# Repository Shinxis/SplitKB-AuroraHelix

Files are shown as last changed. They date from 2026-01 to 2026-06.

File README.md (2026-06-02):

# SplitKB Aurora Helix
An ergonomic split keyboard with ortholinear grid layout, using Aurora Helix from [splitkb.com](https://splitkb.com)

Here are the 3D design files for the keyboard case, including the:
- top plates,
- controller covers,
- bottom plates,
- bottom plate molds for casting them from epoxy.

The files types are:
- The complete 3D model in a FreeCAD file
- The exported parts in STL files
- Bambu Studio project files ready to print on a bambu printer.

<br>

# Build log
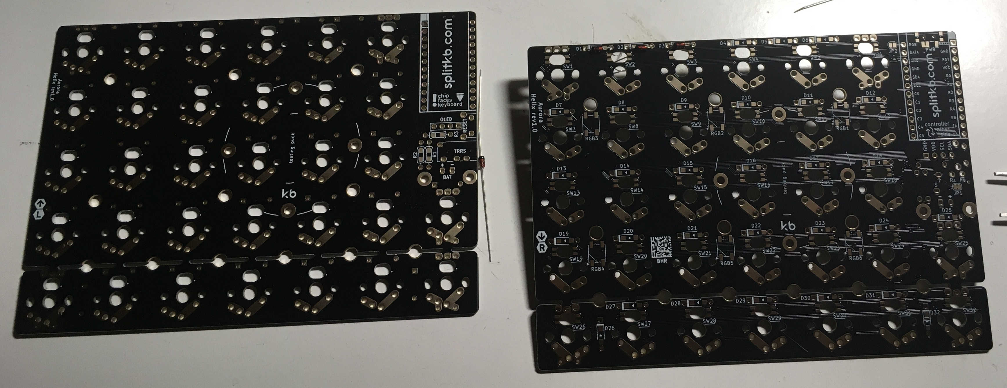
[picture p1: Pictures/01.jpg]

Arrived.

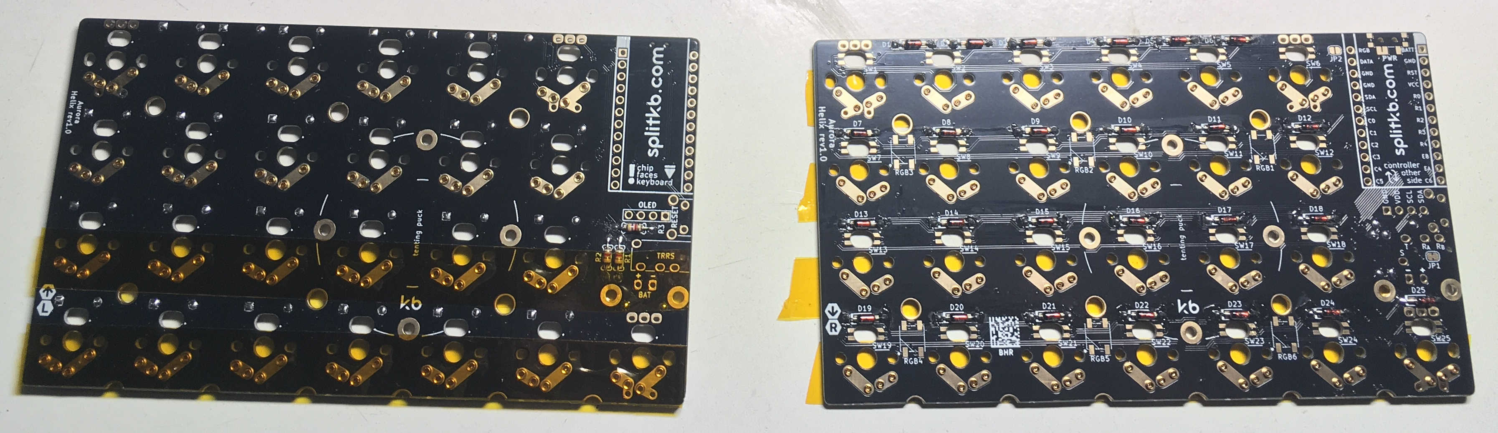
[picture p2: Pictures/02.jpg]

Low row cut off. Using Kapton tape to hold the MillMax sockets and components in place.

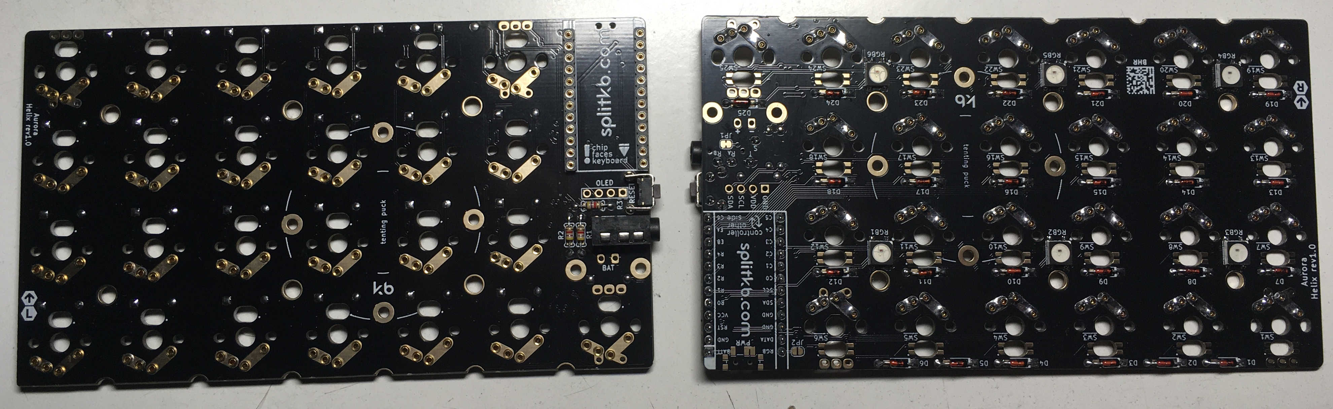
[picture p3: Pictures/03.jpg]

Soldered.

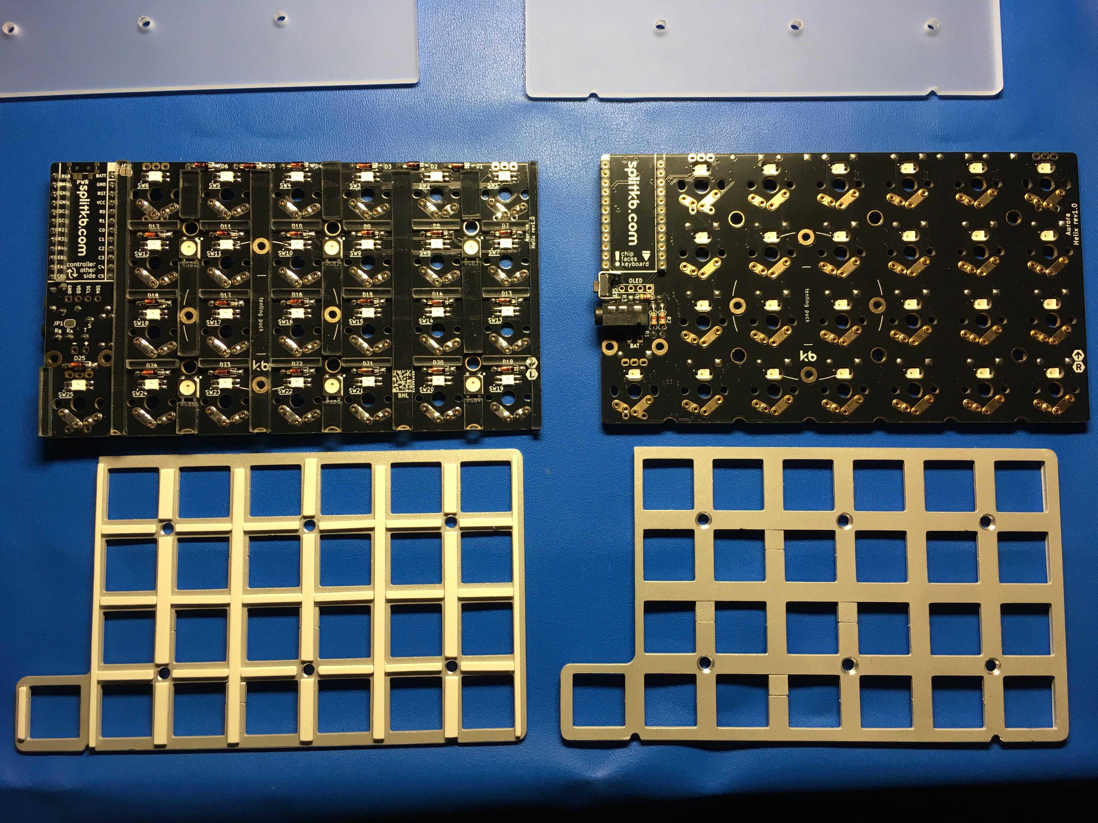
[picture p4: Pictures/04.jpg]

Adding spacers between the plates in order to make a tight stack. Later discarded in order to cut off some height and to use a 3D printed case.

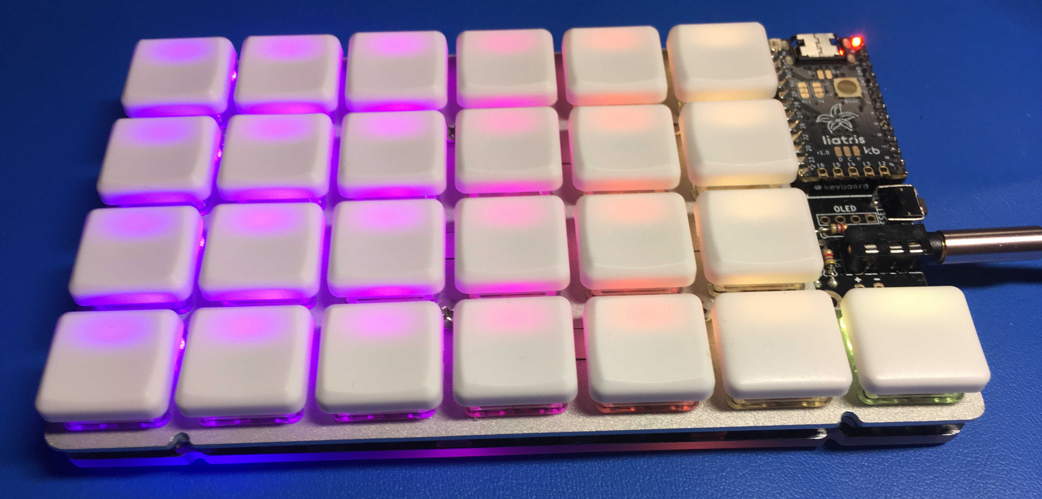
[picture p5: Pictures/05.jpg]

It's working, yay! But... is it perfect?

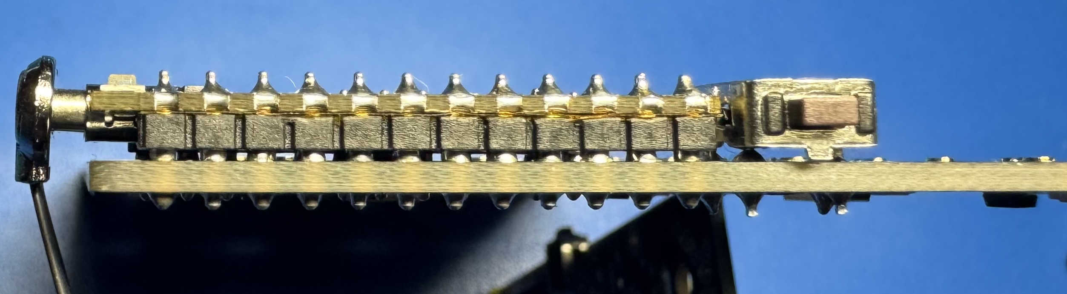
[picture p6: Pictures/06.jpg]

Making it lower. Used pins instead of pin headers on the controller daughterboard. Changed the diodes and resistors to surface-mount versions. Scraped new pads for the I2C pull-up resistors on the bottom side.

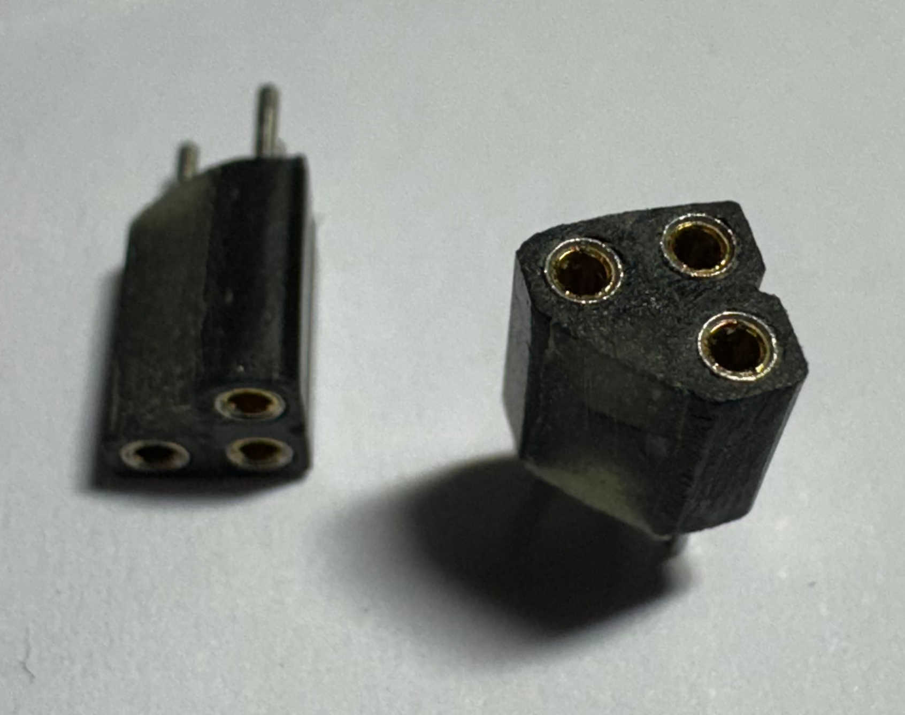
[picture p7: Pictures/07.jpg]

Replace TRRS connector: use 2x2 header pins/sockets with 0.1" spacing (Dupont connectors). Only 3 contacts were required, but in hindsight, using all 4 contacts would have been better (with one corner chamfered). The tolerances turned out to be much better than anticipated. Also didn't have a 3D printer at the time, it would have helped a lot. That's why there isn't any jigs modeled, sorry.

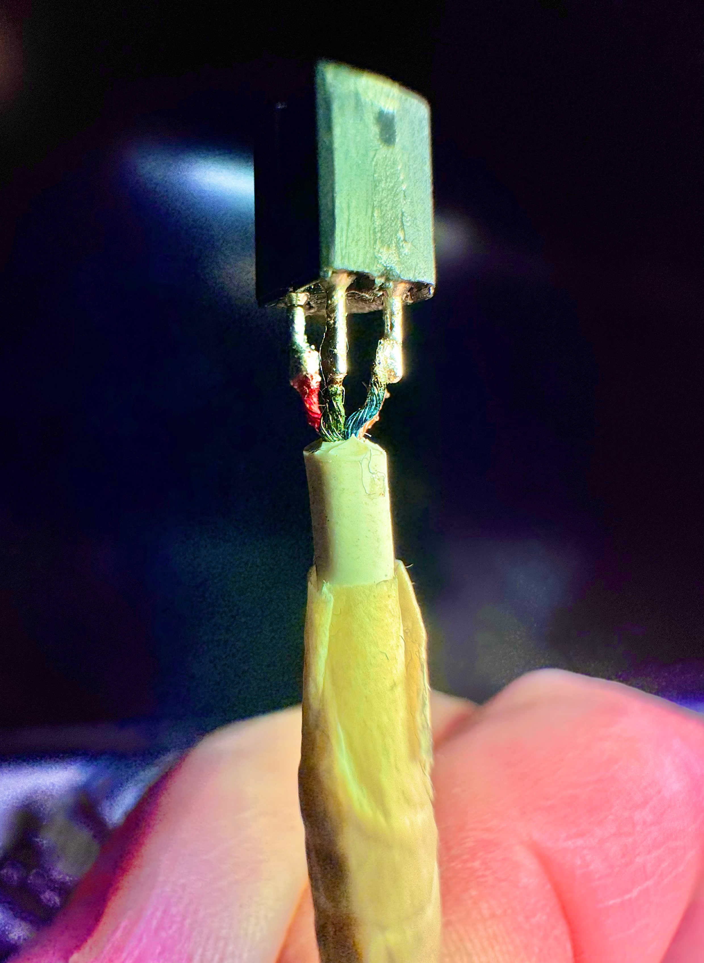
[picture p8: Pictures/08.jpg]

Soldered the wires.

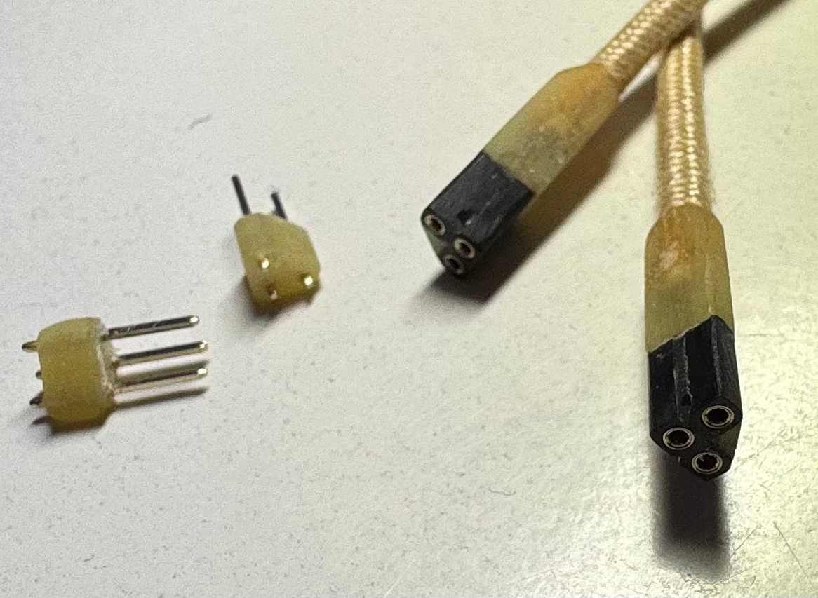
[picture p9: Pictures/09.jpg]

Making the pin receptacle. Inserted the pins into the sockets through crepe masking tape and poured some epoxy glue on it. Then filed down to the right shape.

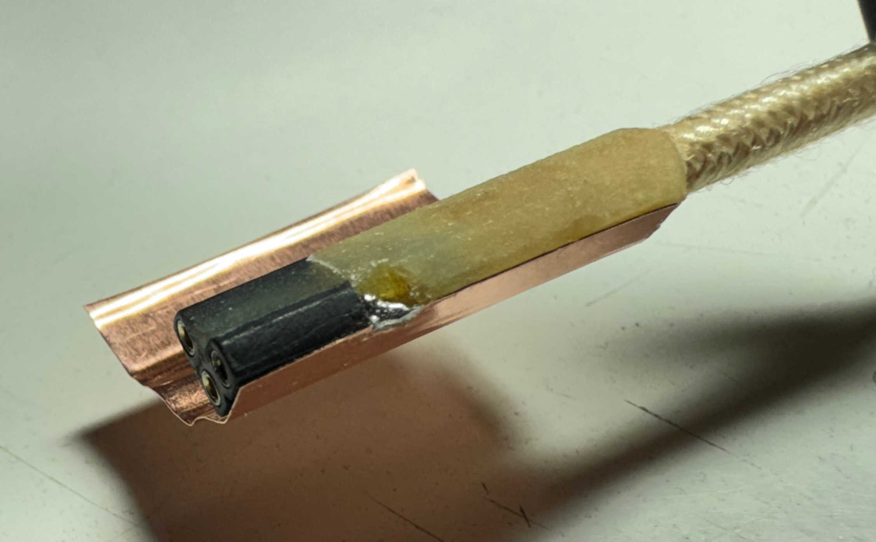
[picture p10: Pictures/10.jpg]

Shielding with 0.005"/0.127mm copper foil sheet.

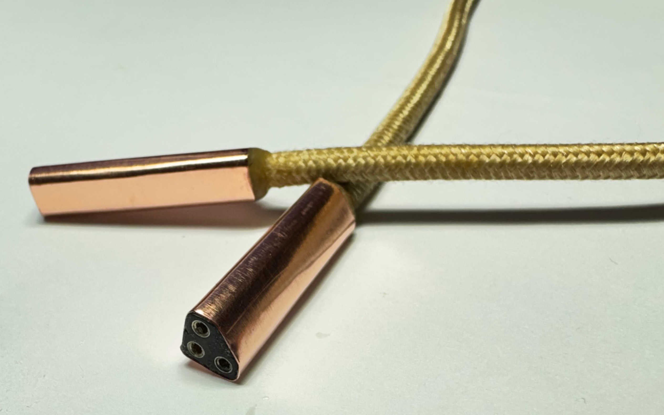
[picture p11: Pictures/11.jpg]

Finished cable with plugs at the ends: bent and glued the shield in place.

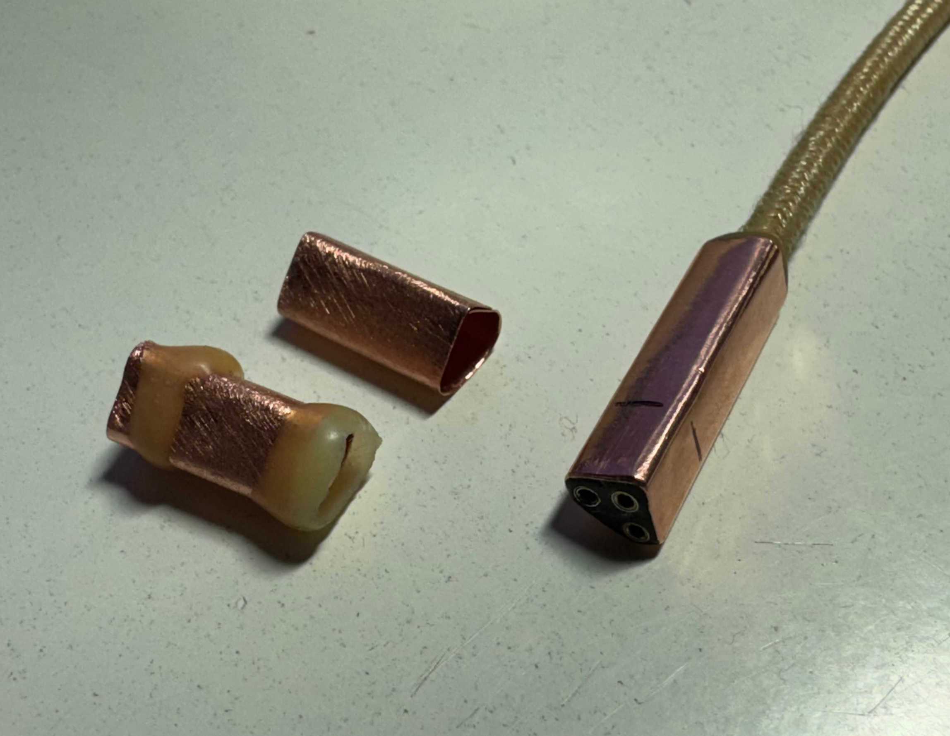
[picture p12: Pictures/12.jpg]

Used the plugs as jigs for the receptacles' shields.

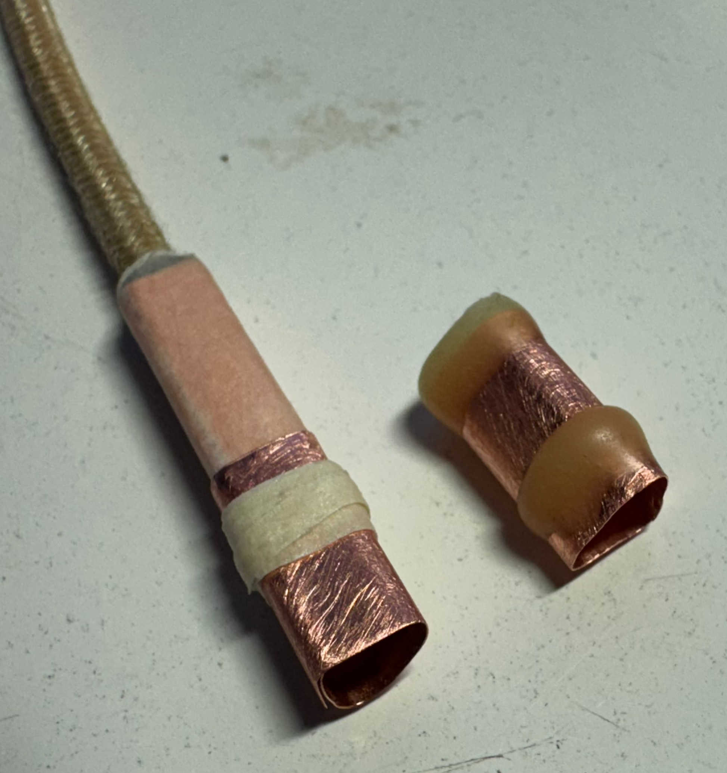
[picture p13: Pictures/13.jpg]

Used masking tape to ensure enough clearance for the plugs to fit. It was maybe even a bit too much.

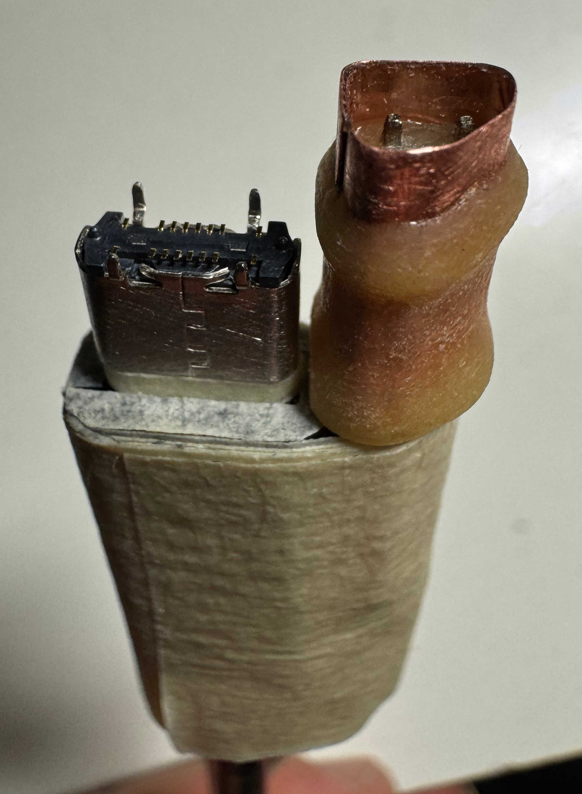
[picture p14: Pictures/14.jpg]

Aligned the connectors.

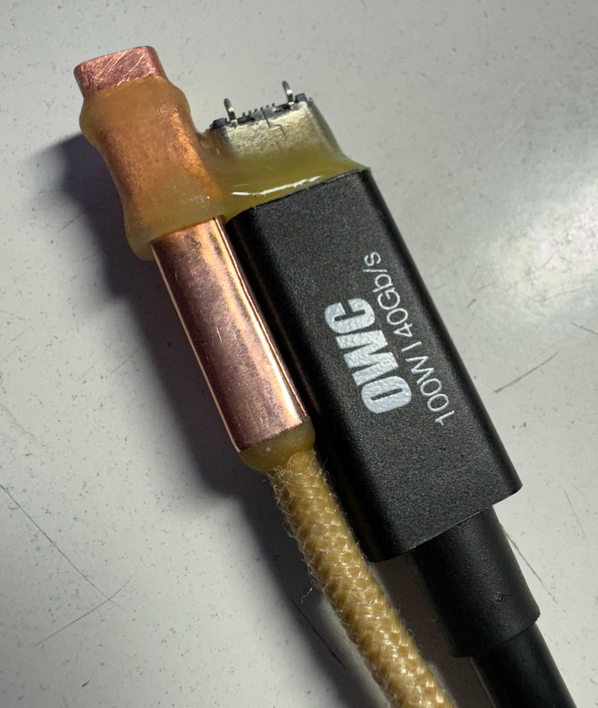
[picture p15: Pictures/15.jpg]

Epoxy \<3

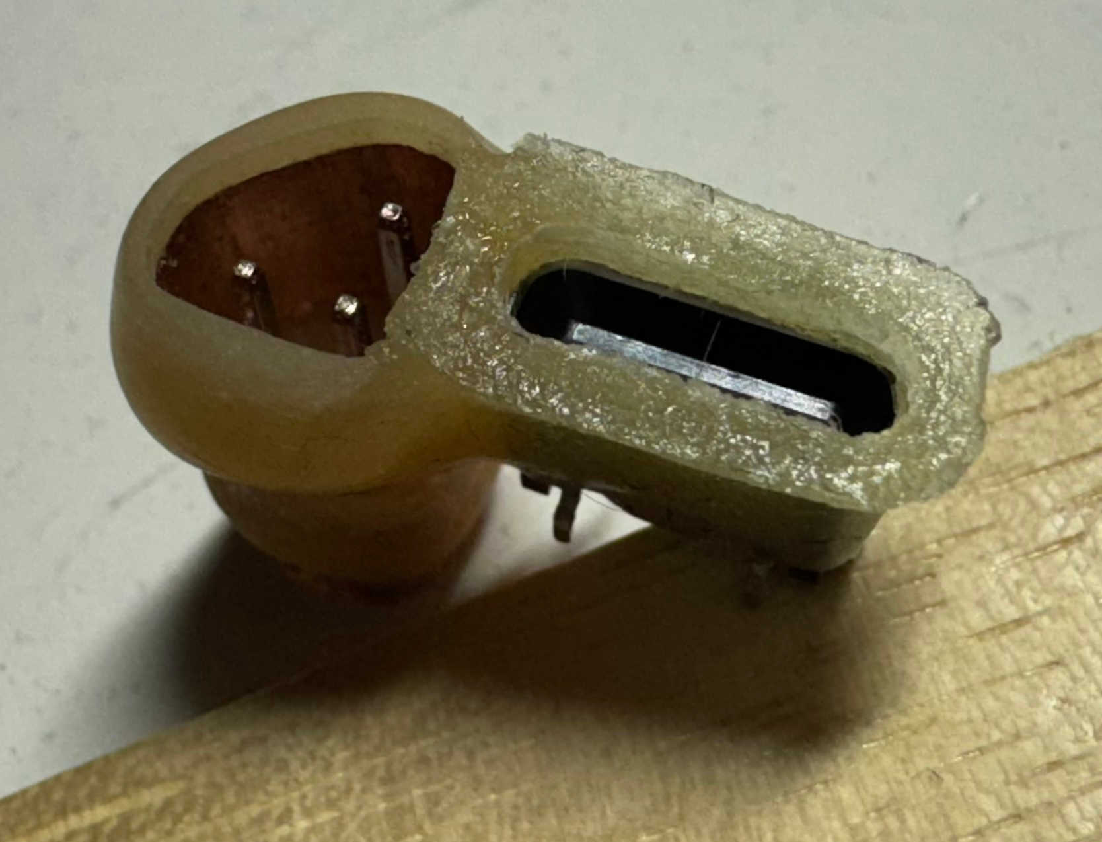
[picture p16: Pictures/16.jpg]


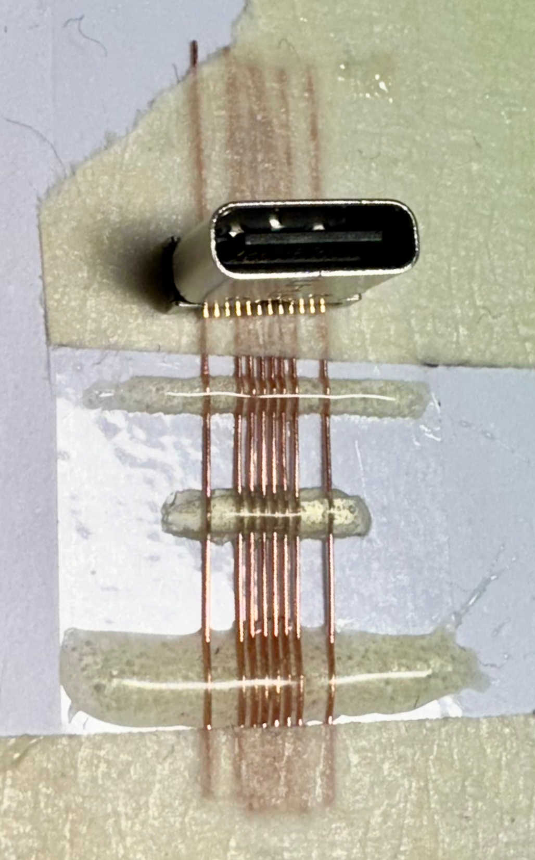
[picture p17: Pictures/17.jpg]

Time for the USB-C extension cable. The connector legs were too small and fragile to be soldered one at a time (one broken connector proved that), so had to try something else.

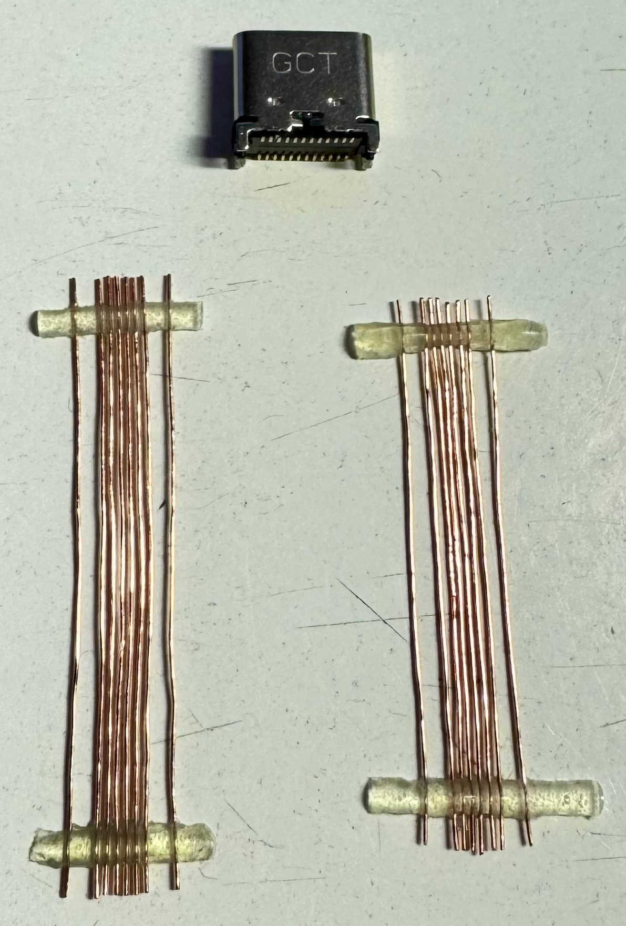
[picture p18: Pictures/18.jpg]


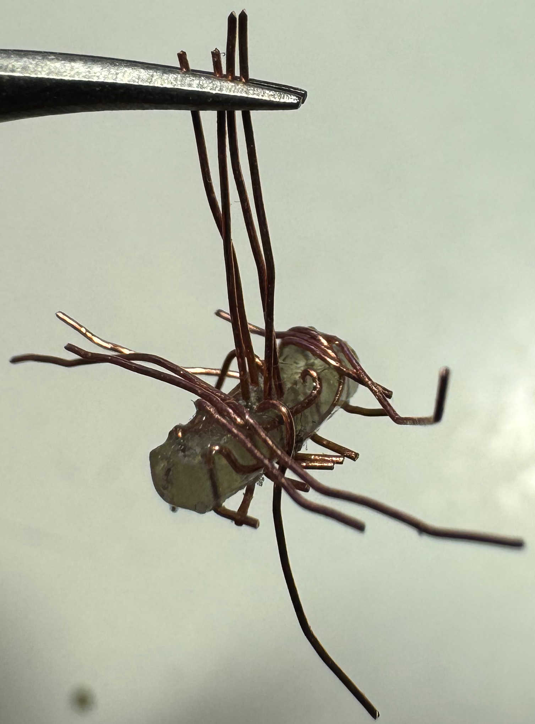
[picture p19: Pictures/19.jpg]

Glued the sides together. This mess turns into beautiful routing.

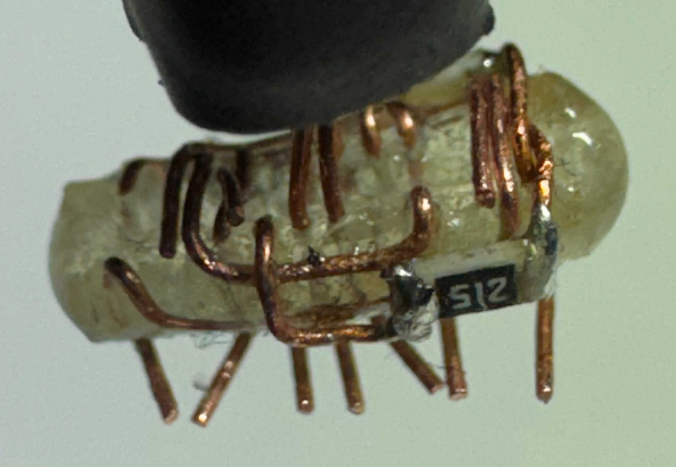
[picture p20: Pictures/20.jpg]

The host facing end receptacle connector. The 5.1K pull-down resistors in CC pins advertise max 3A (\@5V) power draw without Power Delivery. D+ and D- lines of opposite sides can be combined when using USB 2.0 speeds.

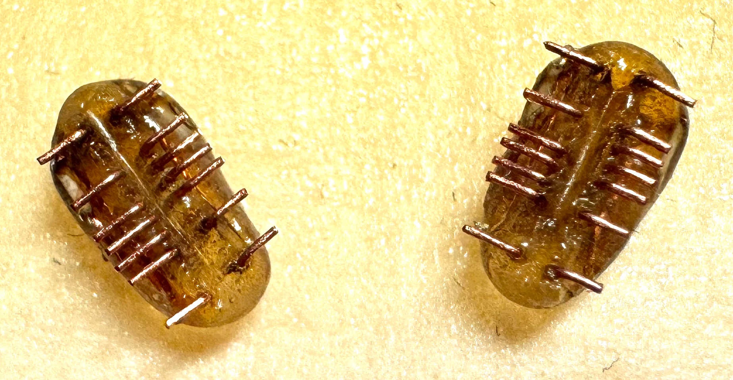
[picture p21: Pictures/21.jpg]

Ready to solder to the connectors.

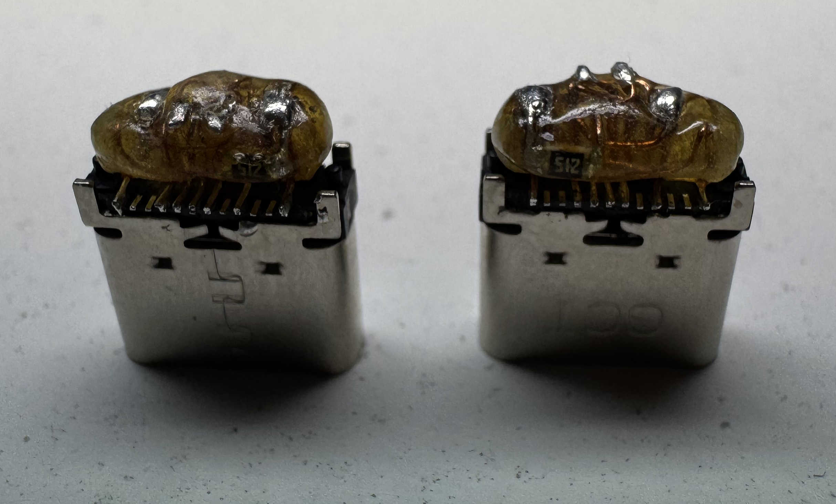
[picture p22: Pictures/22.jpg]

Used a LOT of flux and solder blobs with a bit too large soldering iron tip, then cleaned everything with IPA.

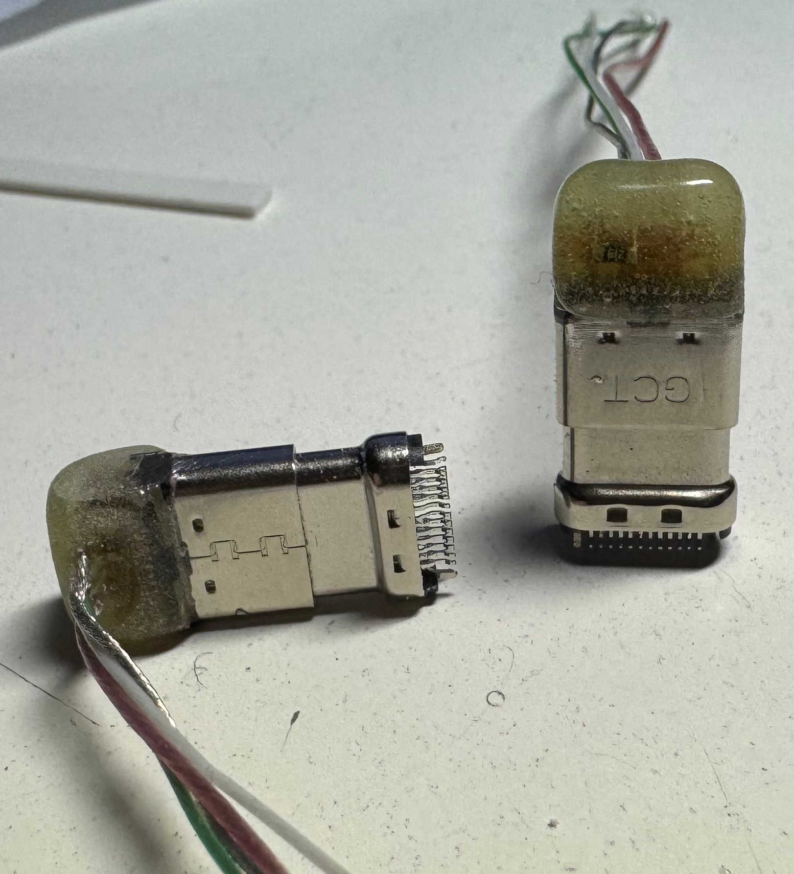
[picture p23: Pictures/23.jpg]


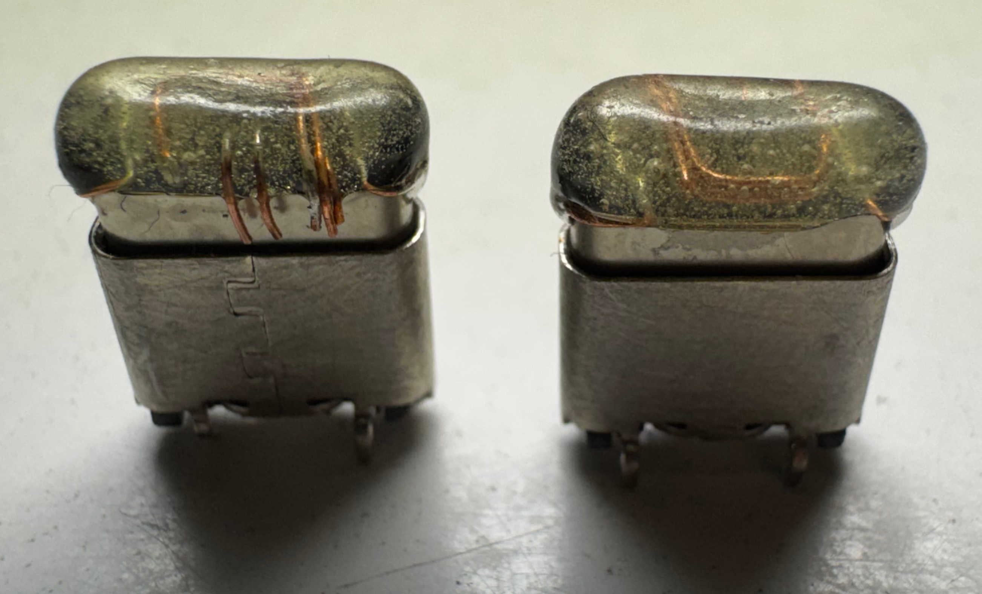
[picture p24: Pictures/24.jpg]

The client end plug connector.

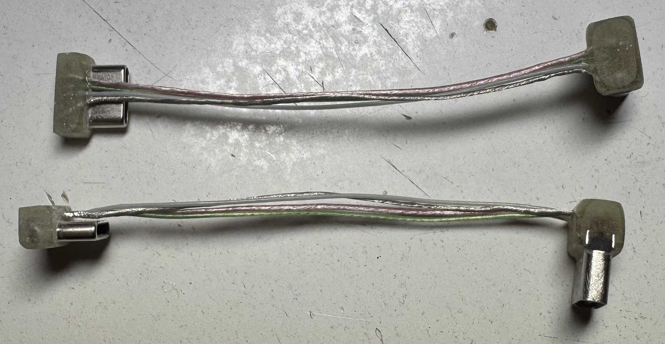
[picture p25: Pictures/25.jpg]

The wires ended up being 15mm too long. At least they fit.

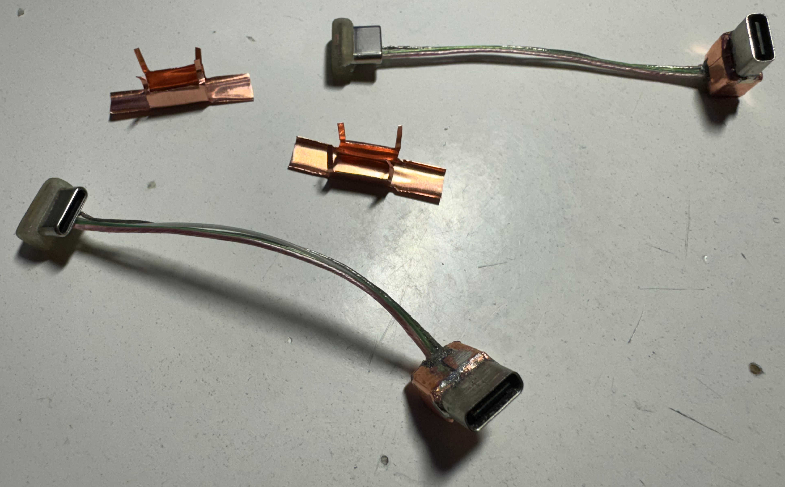
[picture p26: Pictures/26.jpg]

Adding shield. Aluminium foil had too weak connection when just wrapped around and it couldn't be soldered.

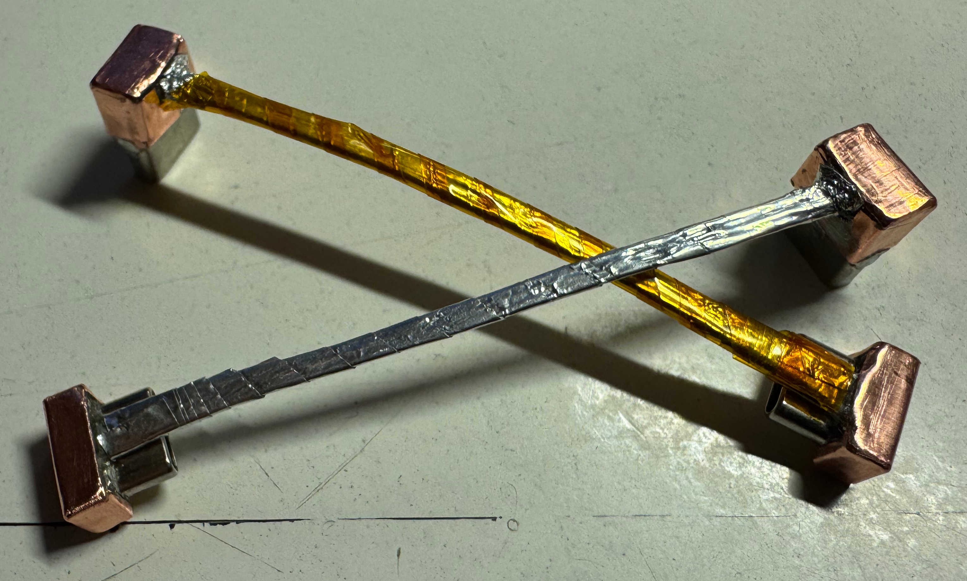
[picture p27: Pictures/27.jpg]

The ground wire is unjacketed and connects to the aluminium foil just enough. The Kapton tape was too thick.

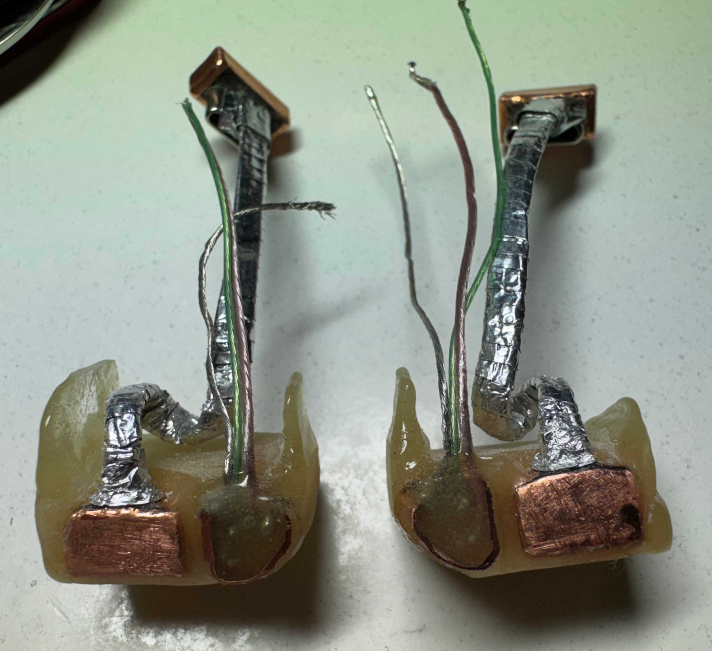
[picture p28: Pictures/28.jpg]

Growing the blob with epoxy. The link cable connector is about to be shut.

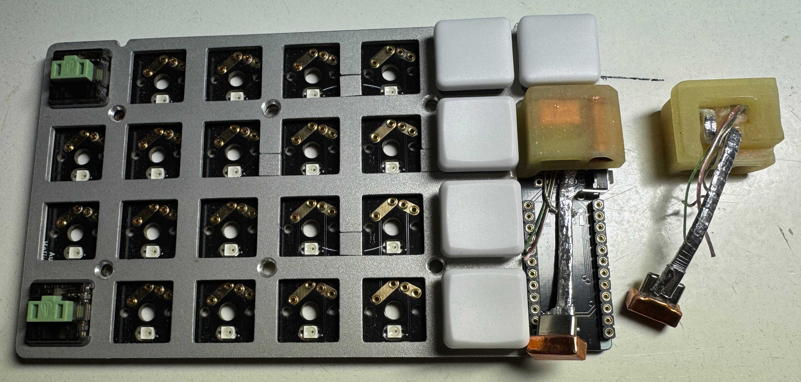
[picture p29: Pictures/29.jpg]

The connector blob gets its dimensions with trial and error, epoxy and filing. If I ever need to do this again, I will definitely use a 3D printer.

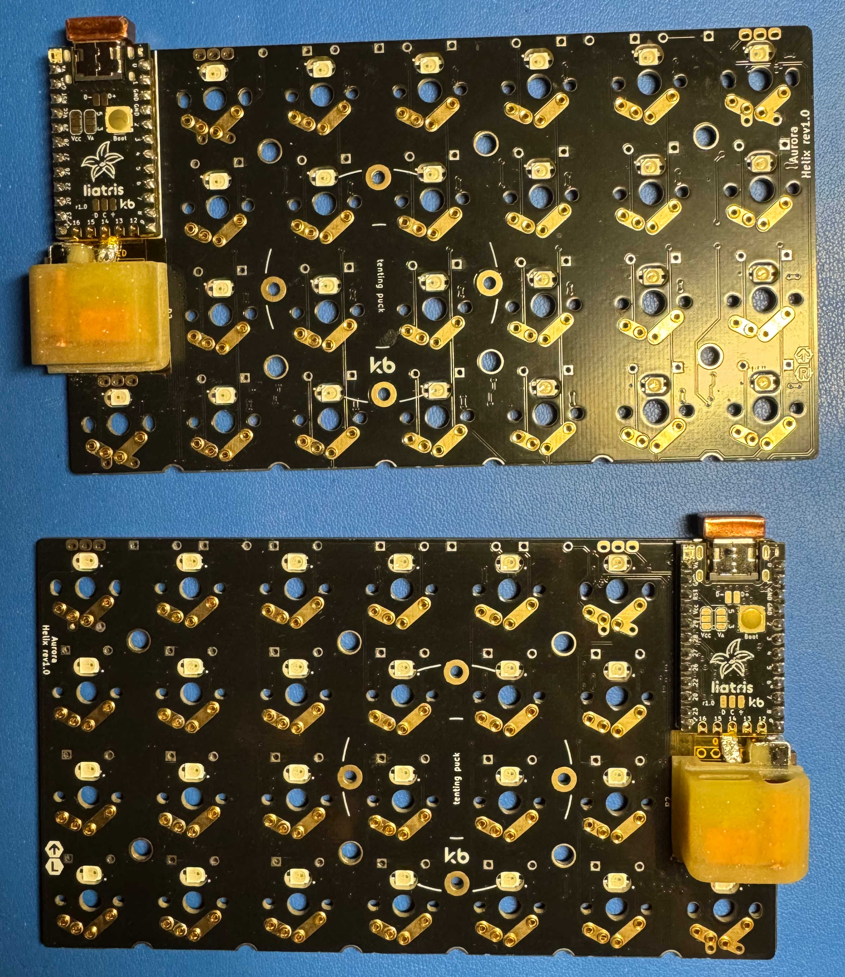
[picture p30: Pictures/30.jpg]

The blob screwed in place. Kapton tape on the main PCB and on the underside of the controller.

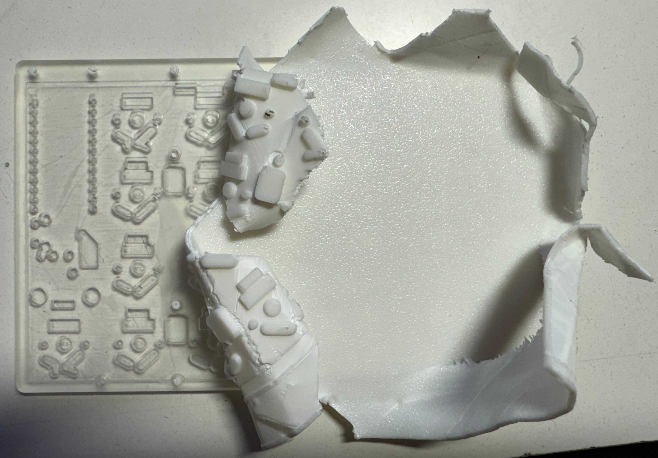
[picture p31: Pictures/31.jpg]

Printed the mold and poured epoxy to make the bottom plate. Gosh, PLA was hard to peel off.

About the rest of the prints... Almost one spool's worth of calibration, trial and error (my first print project ever). 0.1 ... 0.2mm was a good spacing for nested or facing objects. Ironing was best done in the direction of the layer lines. Concentric pattern with 100% infill creates bumps in crossroads like in the top plate. Always first preview what the printer will actually do.

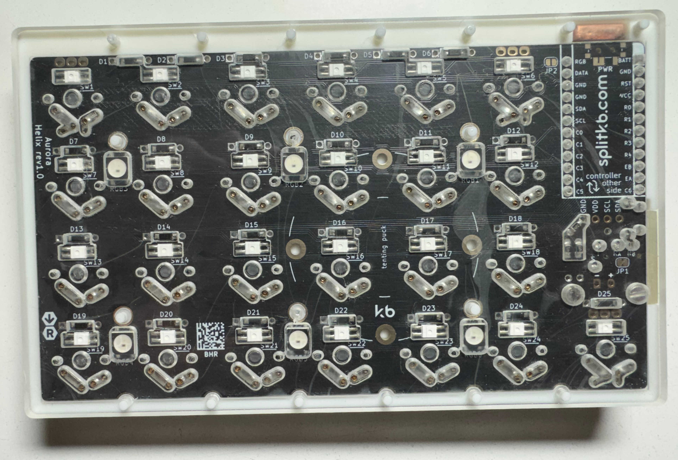
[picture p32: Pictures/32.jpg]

First version of the bottom plate. The matt stripes/waves are caused by isopropyl alcohol dissolving something oily off the PLA surface. Also, tearing the epoxy off the porous surface of the PLA material and the stringed print texture leave marks. Using silicone oil as releasing agent helped marginally, but created issues of its own. Wax may help next... It would be best to seal the print surface with something.

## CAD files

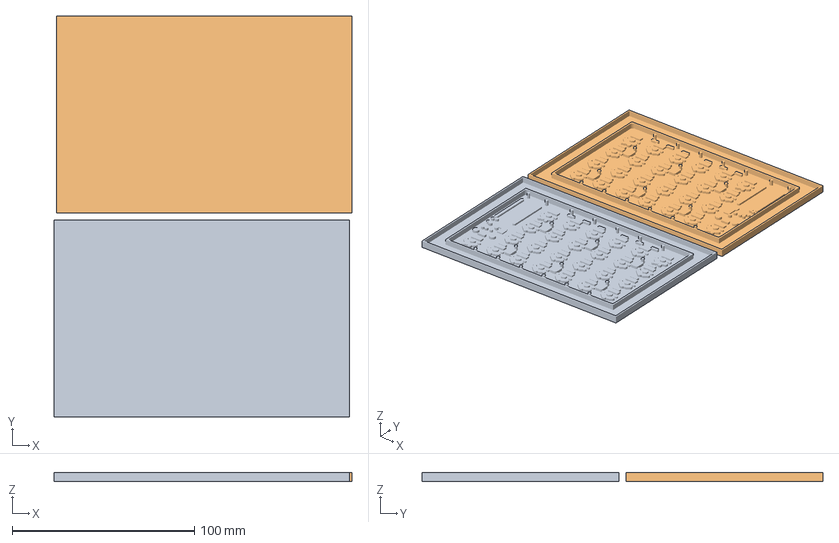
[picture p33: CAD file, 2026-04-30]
Bambu-Studio/HelixCase-Mold.3mf
163.2 x 220.0 x 4.75 mm
HelixCase-MoldLeft.stl
HelixCase-MoldRight.stl

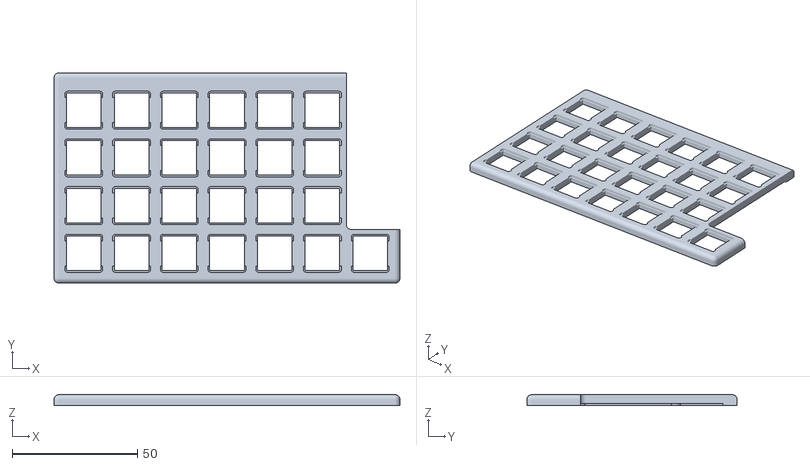
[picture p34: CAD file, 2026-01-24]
STL/HelixCase-TopLeft.stl
138.1 x 83.9 x 4.25

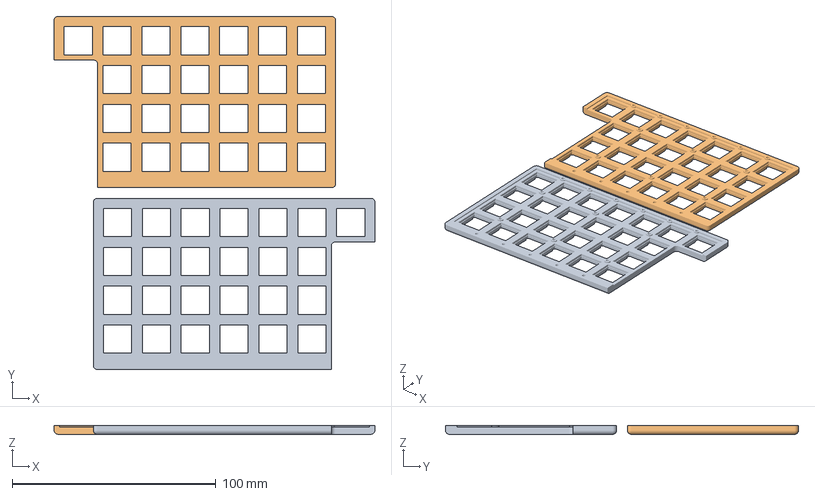
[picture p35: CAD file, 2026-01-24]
Bambu-Studio/HelixCase-Top.3mf
157.4 x 173.1 x 4.25 mm
HelixCase-TopLeft.stl
HelixCase-TopRight.stl

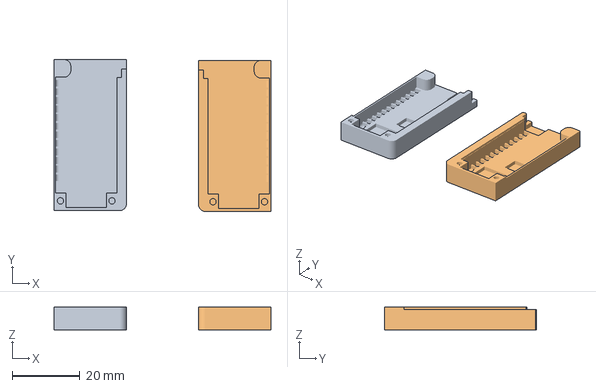
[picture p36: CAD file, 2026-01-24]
Bambu-Studio/HelixCase-Cover.3mf
64.2 x 44.9 x 6.75 mm
HelixCase-CoverLeft.stl
HelixCase-CoverRight.stl

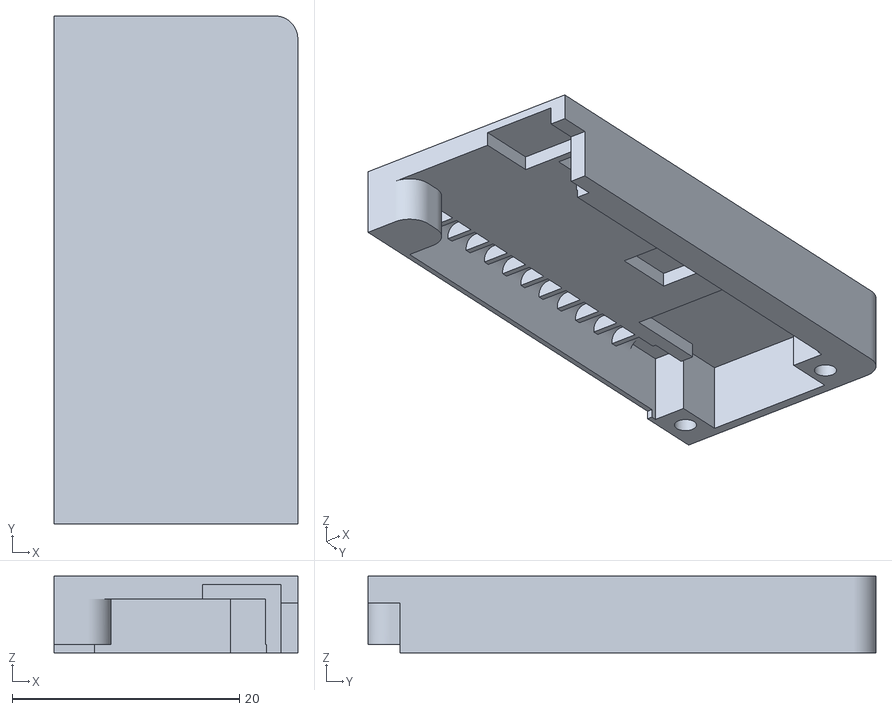
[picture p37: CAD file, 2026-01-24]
STL/HelixCase-CoverLeft.stl
21.4 x 44.7 x 6.75

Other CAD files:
STL/HelixCase-TopRight.stl
STL/HelixCase-CoverRight.stl

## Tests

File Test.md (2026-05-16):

# Headline

Paragraph

- a
- b
- c

continue
